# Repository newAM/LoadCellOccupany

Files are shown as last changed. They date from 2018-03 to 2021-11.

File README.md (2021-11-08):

## Load Cell Occupancy Sensor

### What is it?
This project is a occupancy sensor that uses a load cell for couches and beds, transmitting data to my Home Assistant server via MQTT over Ethernet.

### Why?
Other bed occupancy sensors that I have used in my home automation setup trigger false negatives when rolling around at night.  I use bed occupancy to turn on my lights if I get up at night, and I wanted a faster, more accurate solution.

#### Why PoE?
Wireless home automation devices often make sense only when they are battery powered, if a power cable needs to be run to the device it can carry data too.  Designing a low power wireless device is far more complicated than designing a wired device and running an Ethernet cable.

## Overview
Load cells → HX711 (ADC) → ATMega328P (MCU) → W5100 (Ethernet) → MQTT Broker → Home Assistant

This sensor takes input from 4 load cells, each supporting one leg of a bed or couch.  The load cells are sampled with a ATMega328P (Arduino) using an HX711 load cell ADC.  These samples are then transmitted to an MQTT broker via the Wiznet W5100 (same as Arduino Ethernet shield).

## Project Contents
-  LoadCell_ArduinoCode - firmware for the ATMega328P
-  LoadCell_Case - 3D printable case designed in OpenSCAD
-  LoadCell_Holder - 3D printable holder for the load cells designed in OpenSCAD
-  LoadCell_HomeAssistant - example Home Assistant configuration
-  LoadCell_KiCAD - schematic and PCB

## Media
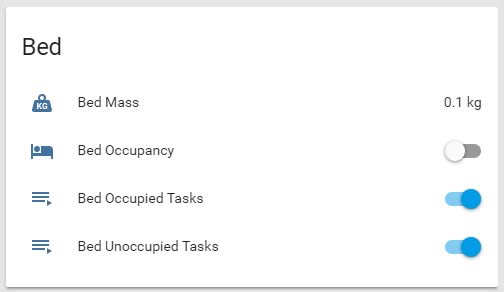
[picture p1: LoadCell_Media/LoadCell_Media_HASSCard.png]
Home Assistant Card


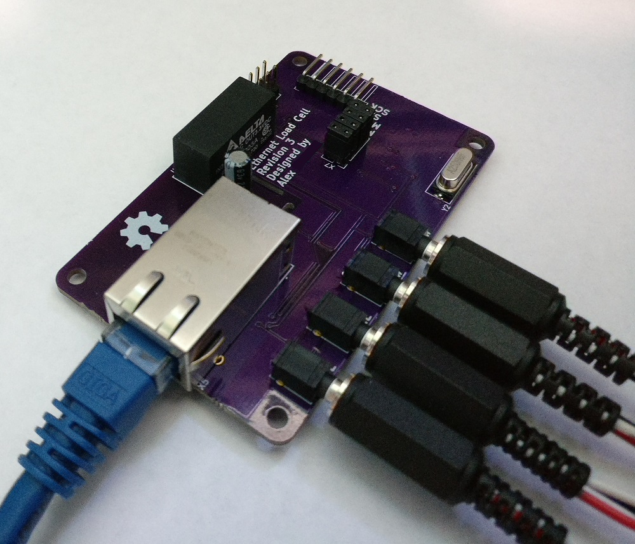
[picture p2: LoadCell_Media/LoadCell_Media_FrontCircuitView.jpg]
Front Circuit View


## Software Used
- [KiCad](http://kicad.org/)
- [Arduino IDE](https://www.arduino.cc/en/Main/Software)
- [OpenSCAD](http://www.openscad.org/)
- [Libre Office](https://www.libreoffice.org/)
- [Home Assistant](https://www.home-assistant.io/)

### Arduino Libraries used
- [Sparkfun HX711 Library](https://github.com/bogde/HX711)
- [Arduino MQTT Client](https://github.com/knolleary/pubsubclient)

## Forks
- [ESP8266 Load Cell](https://github.com/Skaronator/ESP8266-Load-Cell) - wireless edition

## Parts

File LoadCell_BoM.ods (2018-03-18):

Reference | Value | Tolerance | Rating | Package | Digikey P/N | Quantity
Integrated Circuits
U1 | HX711 |  |  | 16-SOIC | N/A | 1
U2 | ATMEGA328P-AU |  |  | 32-TQFP | ATMEGA328P-AU-ND | 1
U3 | NCP1090 |  |  | 8-SOIC | NCP1090DGOS-ND | 1
U4 | PG02S4803A |  |  | 8-SIP | 941-1185-ND | 1
U5 | W5100 |  |  | 80-LQFP (10) | 1278-1002-ND | 1
Resistors | Ohms |  | Watts
R1, R2 | 100 | 1% | 0.1 | 0603 | 311-100HRCT-ND | 2
R3-R6 | 49.9 | 1% | 0.25 | 0805 | RNCP0805FTD49R9CT-ND | 4
R7 | 20k | 1% | 0.1 | 0603 | 311-20.0KHRCT-ND | 1
R8 | 8.2k | 1% | 0.1 | 0603 | 311-8.20KHRCT-ND | 1
R13 | 300 | 1% | 0.1 | 0603 | 311-300HRCT-ND | 1
R9, R14-R16 | 12k | 1% | 0.1 | 0603 | 311-12.0KHRCT-ND | 4
R10 | 24.9k | 1% | 0.1 | 0603 | 311-24.9KHRCT-ND | 1
R11 | 178k | 1% | 0.1 | 0603 | 311-178KHRCT-ND | 1
R12 | 4420 | 1% | 0.1 | 0603 | 311-4.42KHRCT-ND | 1
R17 | 1M | 5% | 0.1 | 0603 | 311-1.0MGRCT-ND | 1
Capacitors | Farads |  | Volts
C1-3,C5-9, C13, C14, C16, C18-21 | 100n | 10% | 16 | 0603 | 1276-1005-1-ND | 14
C4, C12 | 10u | 10% | 10 | 0805 | 1276-6456-1-ND | 2
C15, C17 | 18p | 5% | 50 | 0603 | 1276-1089-1-ND | 2
C10 | 100n | 10% | 100 | 0805 | 1276-6840-1-ND | 1
C11 | 22u | 20% | 63 | 5mm | 493-12798-1-ND | 1
Inductors | Henries |  | Amperes
L1, L2 | 1u | 20% | 600m | 0603 | 445-3163-1-ND | 2
Oscillators | Hertz
Y1 | 8MHz |  |  |  | 490-1195-1-ND | 1
Y2 | 25M | 30ppm |  | HC49 | 535-10235-1-ND | 1
Connectors
X1-X4 | SJ1-2503A |  |  |  | CP1-2503A-ND | 3
X5 | 0813-1X1T-57-F |  |  |  | 507-1421-ND | 1
X6 | ICSP |  |  | 2*3 2.54mm | 952-1779-ND | 1
X7 | SPI Disconnect |  |  | 2*4 2.54mm | 952-2123-ND | 1
X8 | Serial Interface |  |  | 1*5 2.54mm RA | N/A | 1
Diodes
D1, D2 | MDB6S |  |  | 4-MicroDIP | MDB6SFSCT-ND | 2
D3 | SMAJ58A |  |  | SMA | SMAJ58A-E3/61GICT-ND | 1
Transistors
Q1 | MMBT4403 |  |  | SOT-23-3 | MMBT4403LT3GOSCT-ND | 1
Other
2.5mm male stereo connector |  |  |  |  | CP-2501SP-ND | 4
Jumpers |  |  |  |  | S9000-ND | 4
3-conductor wire |  |  |  |  | N/A | 4
PCB |  |  |  |  | N/A | 1
Cheap Ebay load cells |  |  |  |  | N/A | 4
Threaded brass inserts |  |  |  | M3 * 3mm | N/A | 4
M3 Screws |  |  |  | M3 * 3mm | N/A | 4

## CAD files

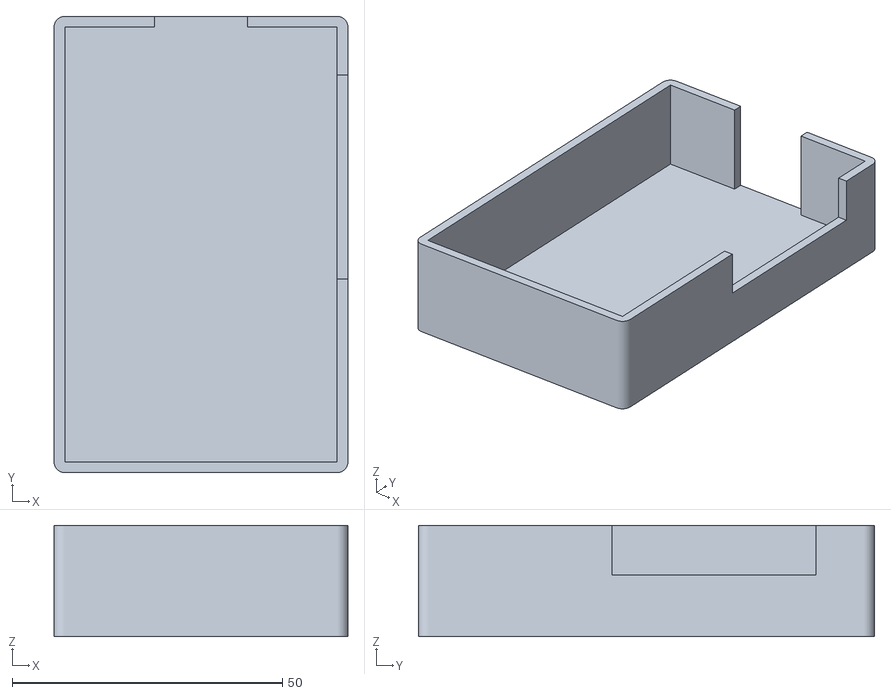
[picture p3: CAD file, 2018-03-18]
LoadCell_Case/LoadCell_Case_Lid.stl
54.4 x 84.4 x 20.6

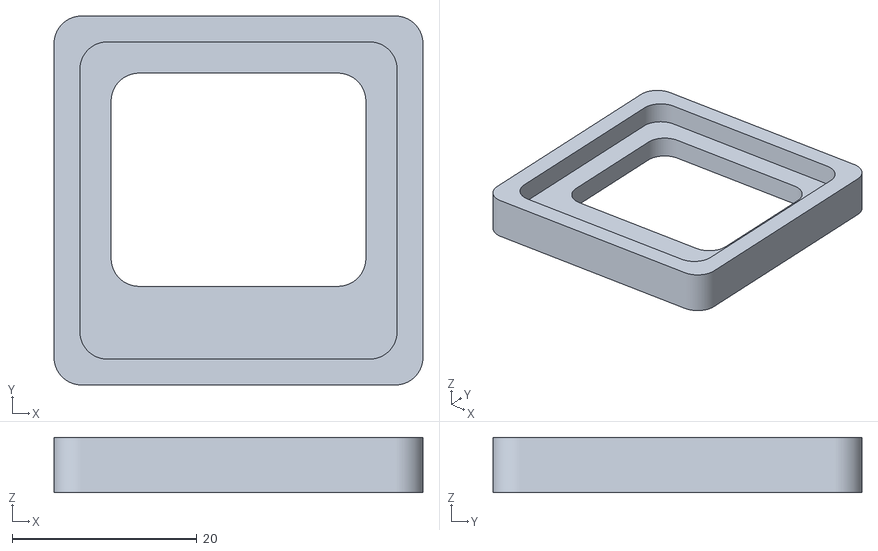
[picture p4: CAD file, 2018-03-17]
LoadCell_Holder/LoadCell_Holder.stl
40.0 x 40.0 x 6.00

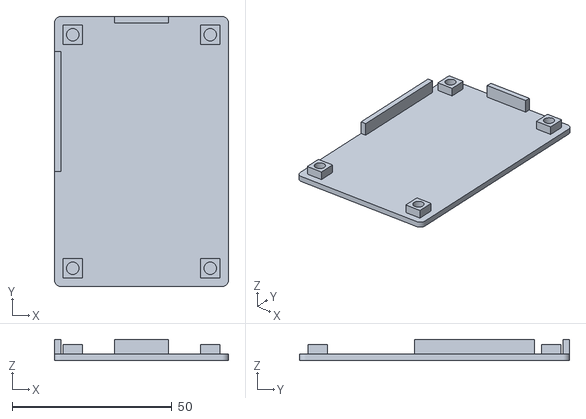
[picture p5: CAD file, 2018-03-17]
LoadCell_Case/LoadCell_Case_Base.stl
54.4 x 84.4 x 6.60

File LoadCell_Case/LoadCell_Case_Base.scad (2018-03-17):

include <LoadCell_Case_Dimensions.scad>;

// screw standoffs
standoff = [heatPad * 2, heatPad * 2, chipH];

// base dimensions
baseSize = [pcbW + (clear + wallW) * 2, pcbL + (clear + wallW) * 2, wallW];

// ethernet wall
baseEthWall = [ethW - clear * 2, wallW, pcbH + chipH];

// TRS wall
baseTrsWall = [wallW, trsRad * 2 + trsSpace * (trsNum - 1), pcbH + chipH];

union() {
    // create base
    RoundCorners(baseSize, roundR);

    // place PCB standoff at each corner
    for (x = [1, -1]) {
        for (y = [1, -1]) {
            translate([(pcbW / 2 - holeX) * x, (pcbL / 2 - holeX) * y, (baseSize[2] + standoff[2]) / 2]) {
                difference() {
                    cube(standoff, center = true);
                    cylinder(h = heatH + cutClear, r = heatR, center = true, $fn = fn);
                }
            }
        }
    }

    // place ethernet wall
    translate([0, (baseSize[1] - baseEthWall[1]) / 2, (baseSize[2] + baseEthWall[2]) / 2]) {
        cube(baseEthWall, center = true);
    }

    // place TRS wall
    translate([-(baseSize[0] - baseTrsWall[0]) / 2, pcbL / 2 - trsCent, (baseSize[2] + baseTrsWall[2]) / 2]) {
        cube(baseTrsWall, center = true);
    }
}

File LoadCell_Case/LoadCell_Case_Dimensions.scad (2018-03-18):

// render settings
fn       = 100;     // sides to render on cylinder
cutClear = 0.001;   // exact cutouts do not render

// clearances
clear = 0.2;    // object to case side
chipH = 3;      // height of chips on board

// PCB dimensions
pcbW = 50;      // width
pcbL = 80;      // length
pcbH = 1.6;     // height

// case dimensions
wallW   = 2;    // wall thickness
roundR  = 2;    // radius of rounded corners
wallCut = wallW + cutClear;

// ethernet cutout sizes
ethH = 13.61 + clear * 2; // 14.00 datasheet recommended
ethW = 16.79 + clear * 2; // 17.55 datasheet recommended

// TRS cutout sizes
trsRad   = 2 + clear;   // radius of cutout for TRS ports
trsSpace = 11;          // spacing between TRS ports 
                        // same as space between first TRS port and PCB edge
trsNum   = 4;           // number of TRS ports
trsCent  = 27.5;        // center of the TRS bank from edge of PCB

// PCB mount points
holeX   = 3.5;                  // distance from hole center to edge of PCB
heatR   = 3.9 / 2;              // radius of hole for heat set insert
heatH   = 3;                    // depth of hole for heat set insert
heatPad = holeX - clear * 2;    // radius of padding around heat set insert

// Makes a cube shape with rounded corners in the z-direction
// dim[x,y,z] - vector containing outer dimensions of the cube
// rad        - radius of the rounded corners 
module RoundCorners(dim, rad) {
    // create adjusted dimensions for corners
    adjDim = [dim[0] - rad * 2, dim[1] - rad * 2, dim[2]];

    hull() {
        // place cylinders at each corner
        for (x = [1, -1])
            for (y = [1, -1])
                translate([x * adjDim[0] / 2,   y * adjDim[1] / 2, 0])
                    cylinder(h = adjDim[2], r = rad, center = true, $fn = fn);

        // place main body
        cube(adjDim, center = true);
    }
}

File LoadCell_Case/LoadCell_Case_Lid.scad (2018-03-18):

include <LoadCell_Case_Dimensions.scad>;

// outer size of lid
lidOuterSize = [pcbW + (clear + wallW) * 2, pcbL + (clear + wallW) * 2, pcbH + chipH + ethH + wallW];

// inner size of lid
lidInnerSize = [pcbW + clear * 2, pcbL + clear * 2, pcbH + chipH + ethH];

// edge of wall
wallEdge = [(pcbW + wallW) / 2 + clear, (pcbL + wallW) / 2 + clear, - lidOuterSize[2] / 2 + wallW];

// ethernet wall cutout for lid
lidEthCutout = [ethW, wallCut, lidInnerSize[2] + cutClear];

// trs cutout for lid
lidTrsCutout = [wallCut, trsRad * 2 + trsSpace * (trsNum - 1) + clear * 2, pcbH + chipH + trsRad * 2 + clear];

difference() {

    // outer dimensions
    RoundCorners(lidOuterSize, roundR);

    // cutout inner dimensions
    translate([0, 0, wallW / 2 + cutClear])
        cube(lidInnerSize, center = true);

    // cutout ethernet hole
    translate([0, wallEdge[1], (lidOuterSize[2] - lidInnerSize[2]) / 2])
        cube(lidEthCutout, center = true);

    // cutout trs hole
    translate([wallEdge[0], pcbL / 2 - trsCent, (lidOuterSize[2] - lidTrsCutout[2]) / 2 + cutClear])
        cube(lidTrsCutout, center = true);
}

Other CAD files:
LoadCell_Holder/LoadCell_Holder.scad

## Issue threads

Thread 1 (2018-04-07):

Can I Make an Adruino Write ESP8266 Firmware?

1043717432, 2018-04-07:
Can you share your homeassistant automated yaml writing?
I am buying esp8266+HX711+Load Cell Occupancy Sensor but I don't know if it is okay to use Arduino.

newAM, 2018-04-29:
Fixed in beb6540b7db2d72ec277a60d8d90185031edf163.

Sorry for taking a while to get to this!

Closed 2018-04-29.

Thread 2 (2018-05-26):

I made a ESP8266 fork which include OTA updates

Skaronator, 2018-05-26:
Thanks @newAM for publishing your work. I wouldn't be able to do this project otherwise. Especially the 3D printed case.

___

In case someone build it's own version with a ESP8266 you might be interested in my fork. It connects via WiFi (obv) and support Over The Air updates.

It also saves the 'tare'/offset to the EEPROM and doesn't reset on restart/power off. And it only sends MQTT updates if the load has changed. (reduce the load on MQTT broker)

https://github.com/Skaronator/ESP8266-Load-Cell

newAM, 2018-06-03:
Thanks for the kind words!  I added your project in the md of mine so people can find it.  I also incorporated the broker load reduction, great idea!

Closed 2018-06-03.

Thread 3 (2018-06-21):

Load cell cable length

danpowell88, 2018-06-21:
How did you extend the length of the wires of the load cells, the ones I found have about 30cm of very thin cable, is it an issue to solder some more wire on an extend this or even better somehow replace it with a thicker cable thats a bit more protected?

newAM, 2018-06-22:
I just got some 3-conductor cable to extend the load cells, with the wires cut to length I have not had any issues.

Closed 2018-06-22.

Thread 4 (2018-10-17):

Strange fluctuations in weight

hammondses, 2018-10-17:
Hi mate,

For some reason I'm getting some pretty huge random fluctuations in weight & can't really work out why, it seems to work pretty well (other than needing to calibrate it so it's actually accurate).

Have a look at the attached image, what does your homeassistant sensor graph look like?

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

newAM, 2018-10-18:
That noise looks very impulsive, my initial guess is that it was a bad connection and shifting weight around is causing breaks, but you still get the noise without a load.  I have logging disabled for mine because it generates a ton of samples, but I am pretty sure I do not have impulses like that since my automation's would trigger when going from loaded to below 0Kg.

My other guess would be power supply noise, has the original schematic been adapted?  If it has, was is your power source?

How wide are those impulses?  If they are just a sample or two this could be cleaned up with a median filter.

hammondses, 2018-10-18:
Yeah i'm using a the esp8266 (somewhat) fork [Link](https://github.com/Skaronator/ESP8266-Load-Cell)

I'm using a 5v 2.1A power supply from my raspberry pi.

How would I tell how wide the impulses are? In the gui logging it shows no data for the sensor.

The points on the graph are always for only a 1 minute time frame, so I'm guessing its a sudden spike which is being recorded.

hammondses, 2018-10-18:
I initially had it setup on my in wall 5v 2a USB port which also gave the same results, swapped to the RPI one figuring it's worth a shot, but no change unfortunately.

I have zero C knowledge unfortunately, I was thinking I could also just do it in homeassistant with a filter, but implementing it at the source would definitely be better.

If you get a chance to have a go at it i'd be really grateful!

newAM, 2018-10-21:
I pushed the code with filter here: https://github.com/newAM/ESP8266-Load-Cell

I did not have the libraries installed to compile it, so if it doesn't build let me know.

Closed 2018-11-24.

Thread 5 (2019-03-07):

few questions

ikrowni, 2019-03-07:
The image of the final product looks different from the boards you mention as the hardware. I would like to have the input jacks and PoE but where do i purchase that specific board?

If my bed has 6 legs will that interfere? I have a purple mattress and it is very very heavy so there are 6 large cylinders for the legs. Can i use 6 load cell sensors just to have it all balanced properly?

newAM, 2019-03-08:
I'm not sure I understand, what is different from my image of the final product?  These boards cannot be purchased fully assembled, I had the PCB fabricated at OSH park and purchased the components on Digikey then soldered it together by hand.

6 legs should be ok, you can modify the design to utilize more load cells if you wish, the HX711 does have another different input that I did not utilize.  It would probably work well enough if you just put spacers under the two extra legs as well.  You mention your bed is heavy though, it is a good idea to double check that the occupants mass + the mass of your bed will not exceed the load cells limit.

Closed 2019-03-21.

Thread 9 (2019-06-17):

W5500 vs W5100

gth758y, 2019-06-17:
Just curious if you saw any technical reason that the Wiznet W5500 chip couldn't be used instead of the W5100 for this application. I'm thinking the 48-LQFP package of the W5500 would be significantly easier to solder than the 80-LQFP of the W5100. I'd have to redesign the board, but that may also reduce the number of caps needed as well.

[W5500 on Digikey](https://www.digikey.com/product-detail/en/wiznet/W5500/1278-1021-ND/4425702)

Looking over the datasheets, it looks to me like there are pins on the W5500 that closely match the pins being used on the W5100, but admittedly this isn't my area of expertise. Thoughts?

newAM, 2019-06-18:
There's no good reason for the decision, other than that the W5100 was what I had on hand when I was prototyping.  I have used the W5500 in my later designs (see: https://github.com/newAM/AmbientSensor) and I much prefer it.

The W5500 has a different PHY, and a slightly different programmers interface (there is an Arduino library though).  Apart from that it should be relatively drop-in.

gth758y, 2019-06-18:
Great, I'll look into implementing it for this. Thanks a bunch!

Closed 2019-06-18.

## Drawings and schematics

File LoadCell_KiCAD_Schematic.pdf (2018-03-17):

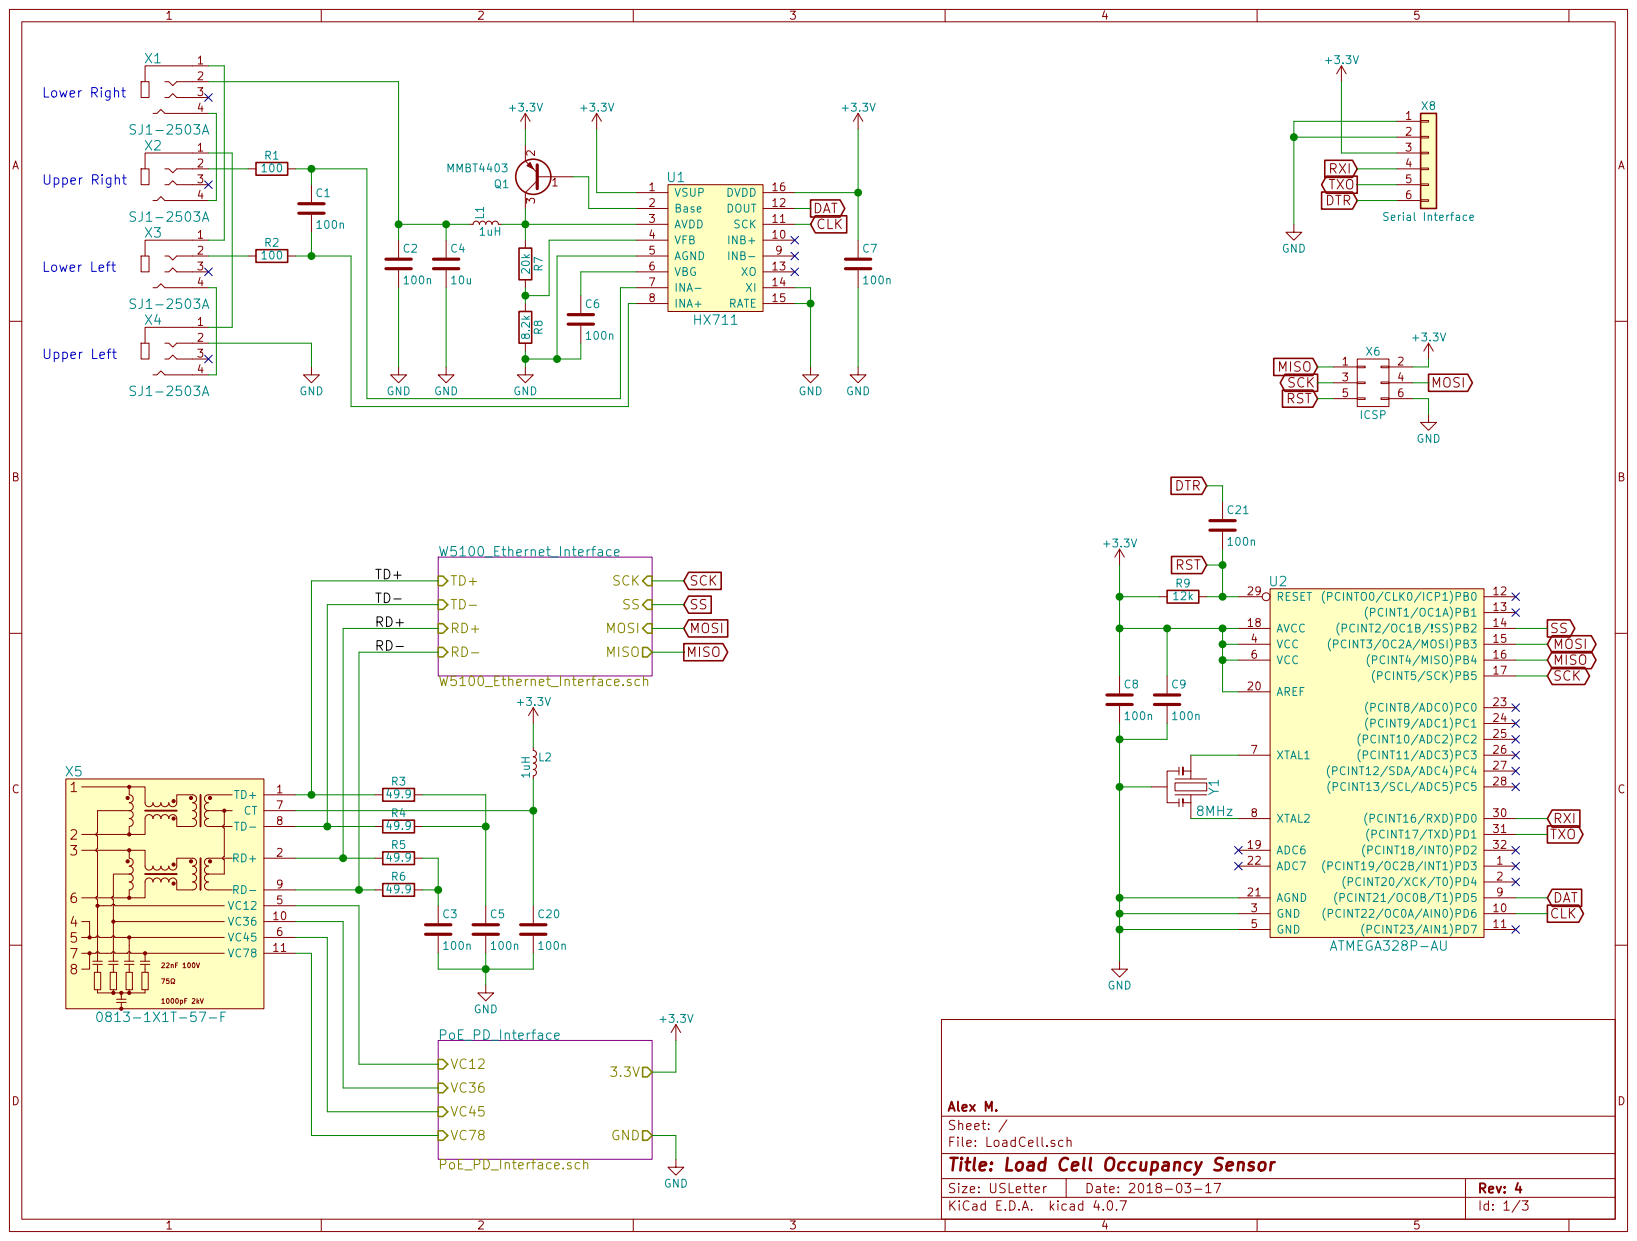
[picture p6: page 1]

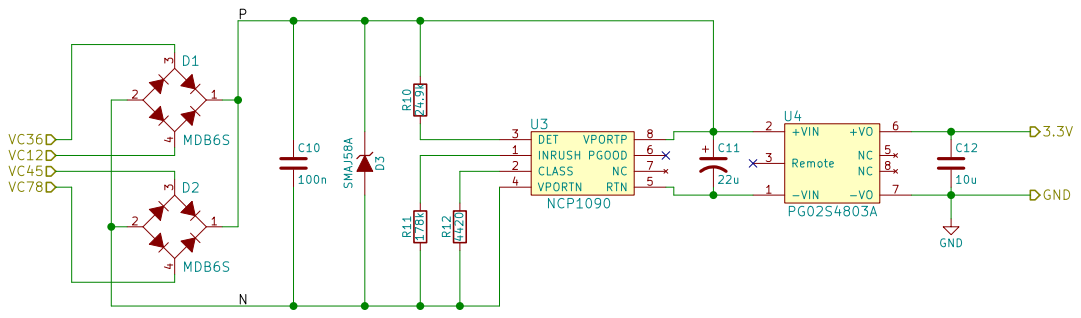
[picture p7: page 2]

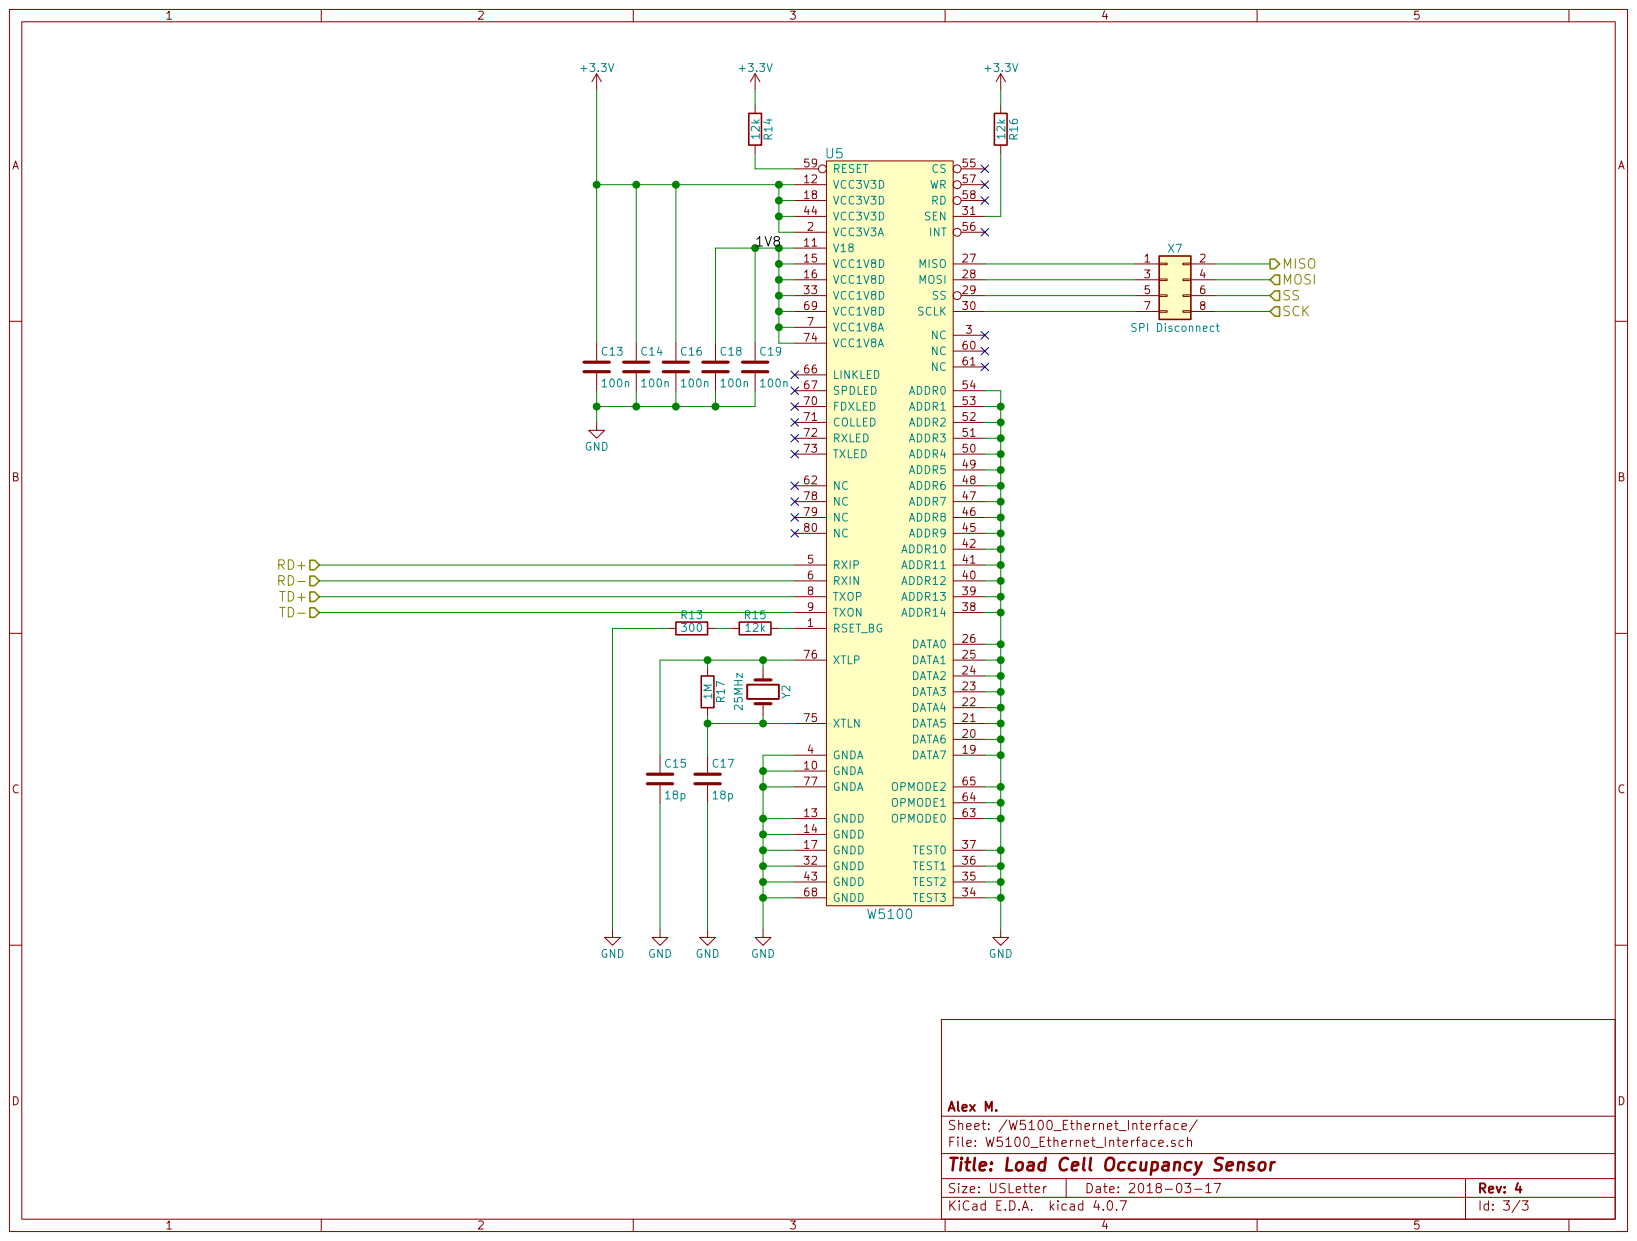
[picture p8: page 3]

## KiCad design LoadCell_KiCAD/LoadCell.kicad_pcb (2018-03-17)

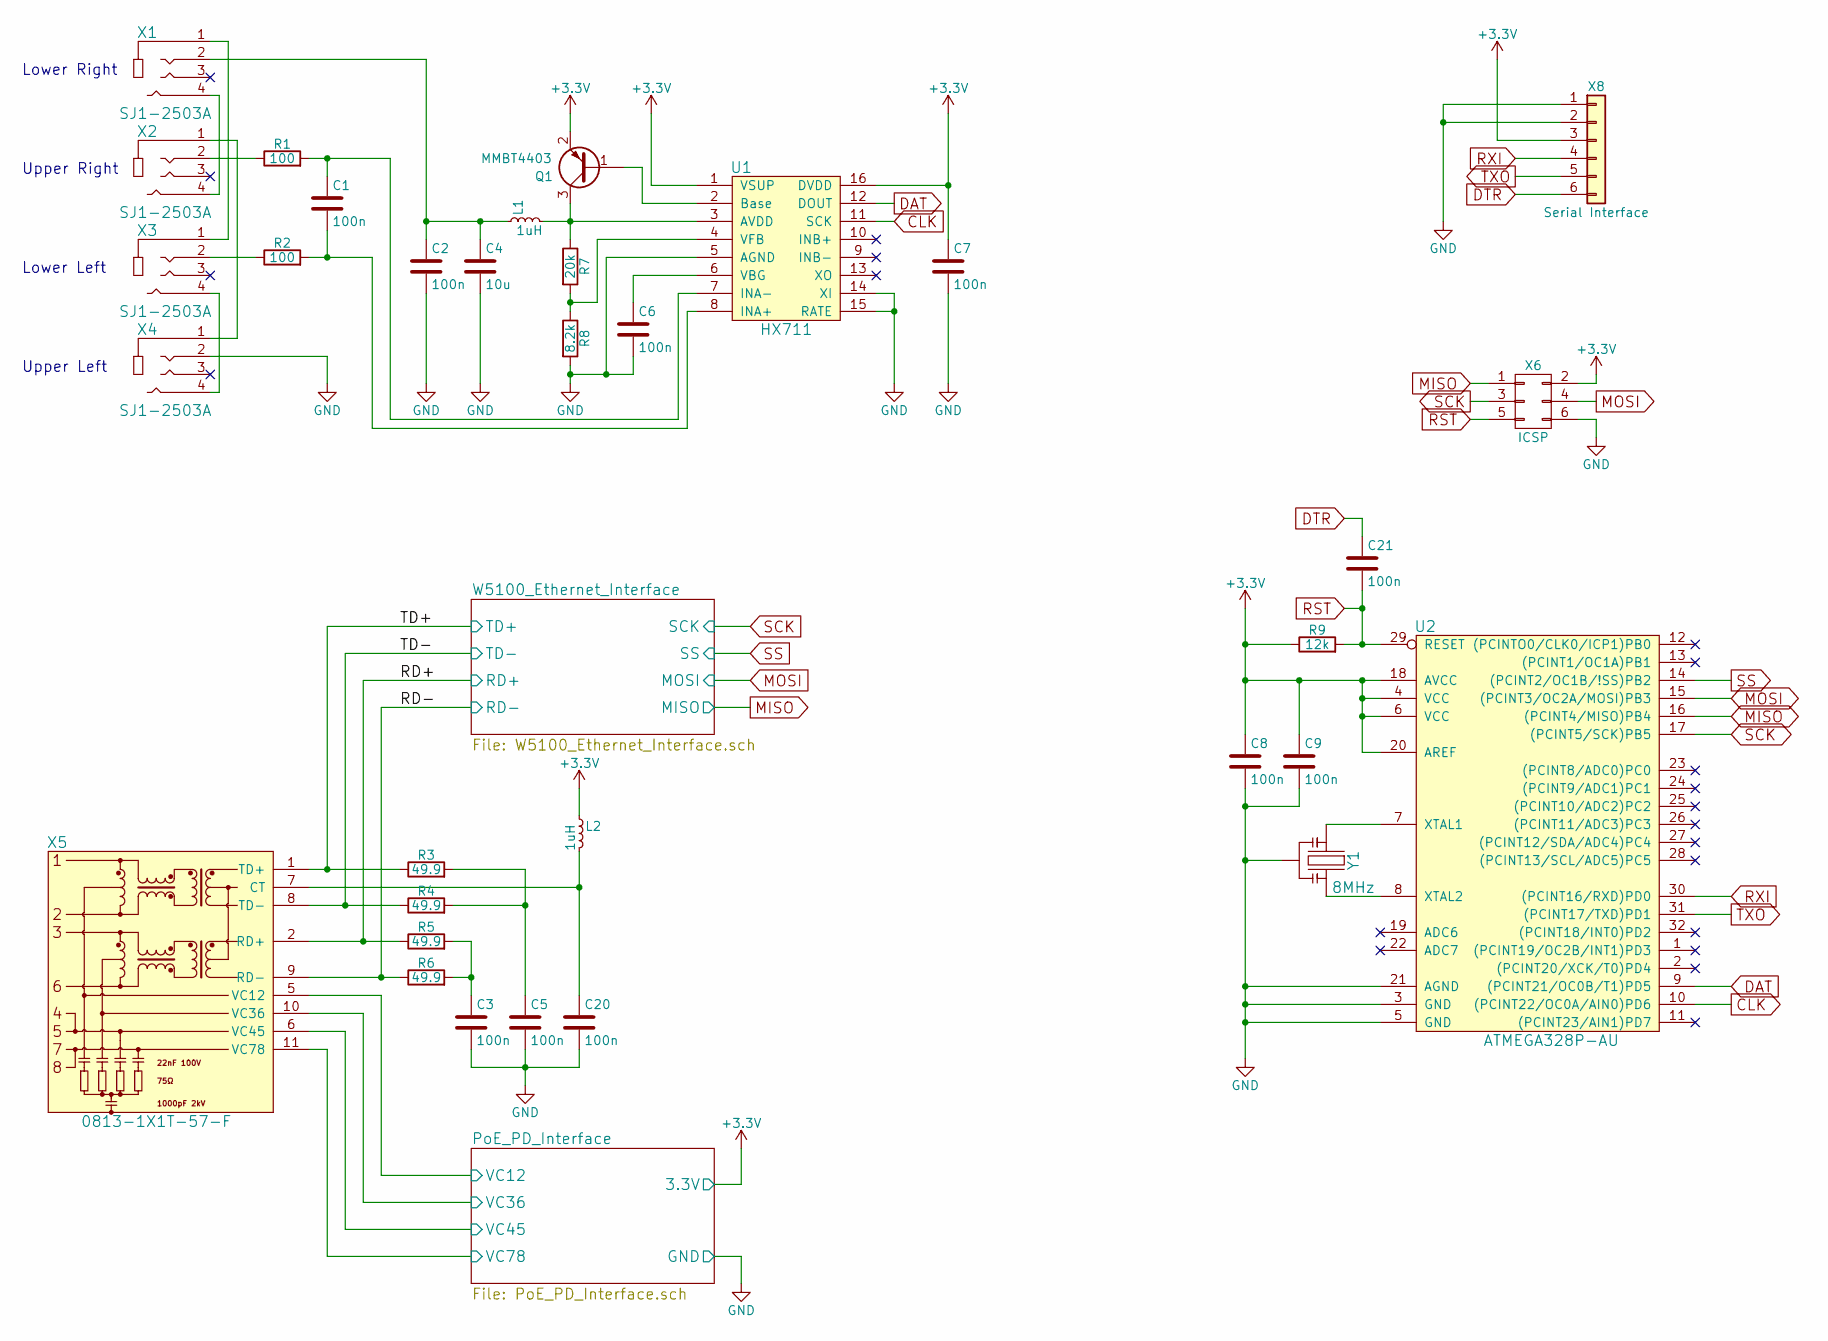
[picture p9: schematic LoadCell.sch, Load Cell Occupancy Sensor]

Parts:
C1, C2, C3, C5, C6, C7, C8, C9, C20, C21: 100n; C_0603; DigiKey Part Number 1276-1005-1-ND
C4: 10u; C_0805; DigiKey Part Number 1276-6456-1-ND
L1, L2: 1uH; C_0603; DigiKey Part Number 445-3163-1-ND
Q1: MMBT4403; SOT-23; DigiKey Part Number MMBT4403LT3GOSCT-ND
R1, R2: 100; R_0603; Tolerance 1%; DigiKey Part Number 311-100HRCT-ND
R3, R4, R5, R6: 49.9; R_0805; DigiKey Part Number RNCP0805FTD49R9CT-ND
R7: 20k; R_0603; Tolerance 1%; DigiKey Part Number 311-20.0KHRCT-ND
R8: 8.2k; R_0603; Tolerance 1%; DigiKey Part Number 311-8.20KHRCT-ND
R9: 12k; R_0603; Tolerance 1%; DigiKey Part Number 311-12.0KHRCT-ND
U1: HX711; SOIC-16_3.9x9.9mm_Pitch1.27mm
U2: ATMEGA328P-AU; TQFP-32_7x7mm_Pitch0.8mm; DigiKey Part Number ATMEGA328P-AU-ND
X1, X2, X3, X4: SJ1-2503A; DigiKey Part Number CP1-2503A-ND
X5: 0813-1X1T-57-F; 0813-1X1T-57-F_RJ45-Jack; DigiKey Part Number 507-1421-ND
X6: ICSP; Pin_Header_Straight_2x03_Pitch2.54mm
X8: Serial Interface; Pin_Header_Angled_1x06_Pitch2.54mm
Y1: 8MHz; CERALOCK_CSTCE_Resonator; DigiKey Part Number 490-1195-1-ND

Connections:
+3V3: C7.1, C8.1, C9.1, L2.1, Q1.2 (E), R9.1, U1.1 (VSUP), U1.16 (DVDD), U2.4 (VCC), U2.6 (VCC), U2.18 (AVCC), U2.20 (AREF), X6.2, X8.3; also elsewhere on the board
/PoE_PD_Interface/VC12: X5.5 (VC12); also elsewhere on the board
/PoE_PD_Interface/VC36: X5.10 (VC36); also elsewhere on the board
/PoE_PD_Interface/VC45: X5.6 (VC45); also elsewhere on the board
/PoE_PD_Interface/VC78: X5.11 (VC78); also elsewhere on the board
/RD+: R5.1, X5.2 (RD+); also elsewhere on the board
/RD-: R6.1, X5.9 (RD-); also elsewhere on the board
/TD+: R3.1, X5.1 (TD+); also elsewhere on the board
/TD-: R4.1, X5.8 (TD-); also elsewhere on the board
CLK: U1.11 (SCK), U2.10 ((PCINT22/OC0A/AIN0)PD6)
DAT: U1.12 (DOUT), U2.9 ((PCINT21/OC0B/T1)PD5)
DTR: C21.1, X8.6
GND: C2.2, C3.2, C4.2, C5.2, C6.2, C7.2, C8.2, C9.2, C20.2, R8.2, U1.5 (AGND), U1.14 (XI), U1.15 (RATE), U2.3 (GND), U2.5 (GND), U2.21 (AGND), X4.2, X6.6, X8.1, X8.2, Y1.2; also elsewhere on the board
MISO: U2.16 ((PCINT4/MISO)PB4), X6.1; also elsewhere on the board
MOSI: U2.15 ((PCINT3/OC2A/MOSI)PB3), X6.4; also elsewhere on the board
unnamed: C1.1, R1.2, U1.7 (INA-)
unnamed: C1.2, R2.2, U1.8 (INA+)
unnamed: C2.1, C4.1, L1.1, X1.2
unnamed: C3.1, R5.2, R6.2
unnamed: C5.1, R3.2, R4.2
unnamed: C6.1, U1.6 (VBG)
unnamed: C20.1, L2.2, X5.7 (CT)
unnamed: L1.2, Q1.3 (C), R7.1, U1.3 (AVDD)
unnamed: Q1.1 (B), U1.2 (Base)
unnamed: R1.1, X2.2
unnamed: R2.1, X3.2
unnamed: R7.2, R8.1, U1.4 (VFB)
unnamed: U2.7 (XTAL1), Y1.1
unnamed: U2.8 (XTAL2), Y1.3
unnamed: X1.1 (Case), X3.1 (Case)
unnamed: X1.4, X2.4
unnamed: X2.1 (Case), X4.1 (Case)
unnamed: X3.4, X4.4
RST: C21.2, R9.2, U2.29 (RESET), X6.5
RXI: U2.30 ((PCINT16/RXD)PD0), X8.4
SCK: U2.17 ((PCINT5/SCK)PB5), X6.3; also elsewhere on the board
SS: U2.14 ((PCINT2/OC1B/!SS)PB2); also elsewhere on the board
TXO: U2.31 ((PCINT17/TXD)PD1), X8.5

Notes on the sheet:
Upper Left
Lower Right
Upper Right
Lower Left

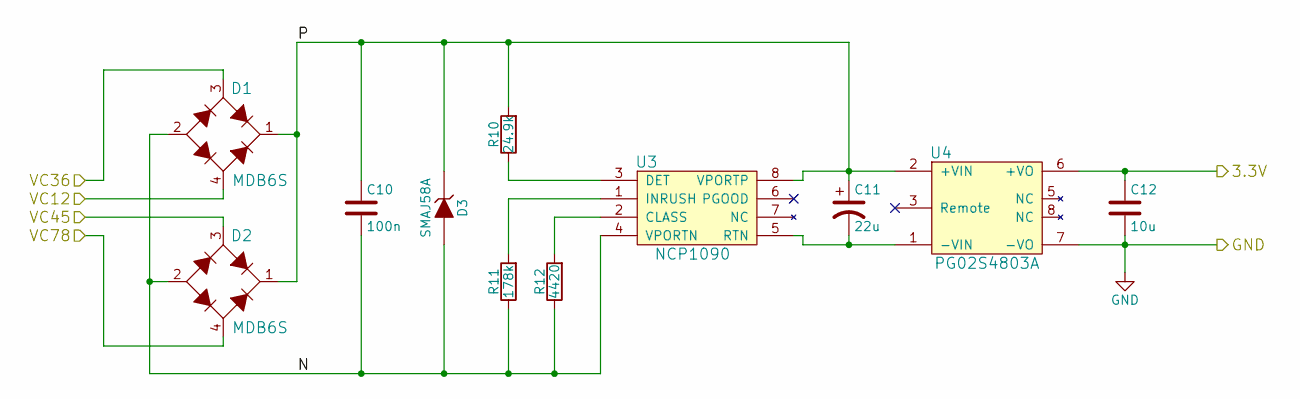
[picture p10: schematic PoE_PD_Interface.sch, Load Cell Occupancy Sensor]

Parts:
C10: 100n; C_0805; DigiKey Part Number 1276-6840-1-ND
C11: 22u; CP_Radial_D5.0mm_P2.00mm; DigiKey Part Number 493-12798-1-ND
C12: 10u; C_0805; DigiKey Part Number 1276-6456-1-ND
D1, D2: MDB6S; Micro-DIP-4; DigiKey Part Number MDB6SFSCT-ND
D3: SMAJ58A; D_SMA; DigiKey Part Number SMAJ58A-E3/61GICT-ND
R10: 24.9k; R_0603; DigiKey Part Number 311-24.9KHRCT-ND
R11: 178k; R_0603; DigiKey Part Number 311-178KHRCT-ND
R12: 4420; R_0603; DigiKey Part Number 311-4.42KHRCT-ND
U3: NCP1090; SOIC-8_3.9x4.9mm_Pitch1.27mm; DigiKey Part Number NCP1090DGOS-ND
U4: PG02S4803A; PG02S; DigiKey Part Number 941-1185-ND

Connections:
+3V3: C12.1, U4.6 (+VO); also elsewhere on the board
/PoE_PD_Interface/N: C10.2, D1.2 (-), D2.2 (-), D3.2 (A), R11.1, R12.1, U3.4 (VPORTN)
/PoE_PD_Interface/P: C10.1, C11.1, D1.1 (+), D2.1 (+), D3.1 (K), R10.2, U3.8 (VPORTP), U4.2 (+VIN)
/PoE_PD_Interface/VC12: D1.4 (AC2); also elsewhere on the board
/PoE_PD_Interface/VC36: D1.3 (AC1); also elsewhere on the board
/PoE_PD_Interface/VC45: D2.3 (AC1); also elsewhere on the board
/PoE_PD_Interface/VC78: D2.4 (AC2); also elsewhere on the board
GND: C12.2, U4.7 (-VO); also elsewhere on the board
unnamed: C11.2, U3.5 (RTN), U4.1 (-VIN)
unnamed: R10.1, U3.3 (DET)
unnamed: R11.2, U3.1 (INRUSH)
unnamed: R12.2, U3.2 (CLASS)

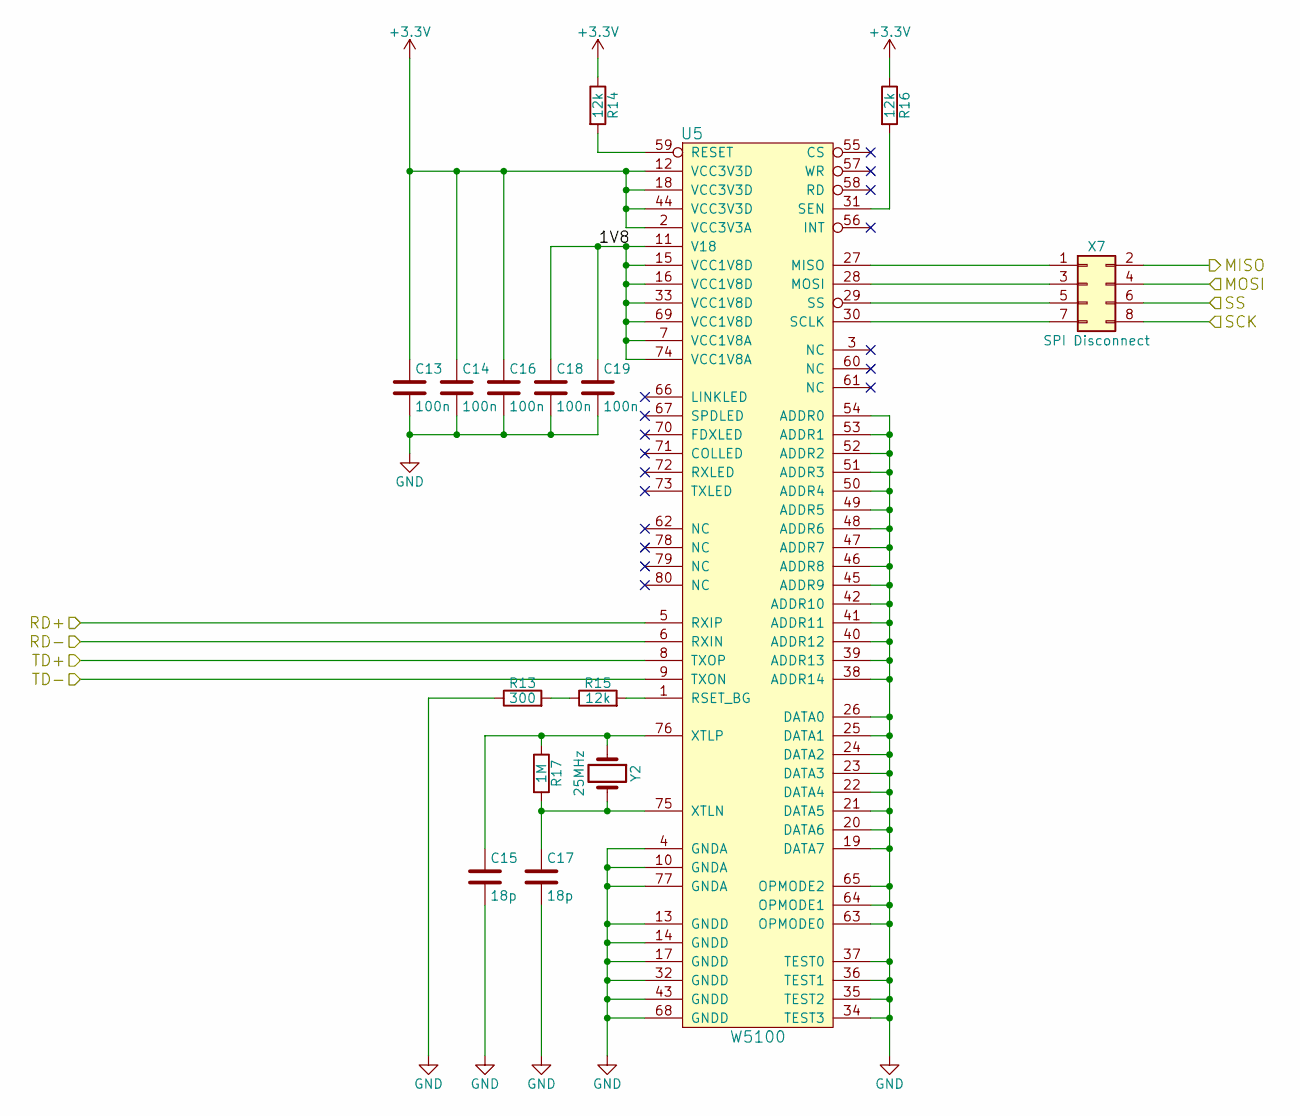
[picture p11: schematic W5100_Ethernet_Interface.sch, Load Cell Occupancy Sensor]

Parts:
C13, C14, C16, C18, C19: 100n; C_0603; DigiKey Part Number 1276-1005-1-ND
C15, C17: 18p; C_0603; DigiKey Part Number 1276-1089-1-ND
R13: 300; R_0603; Tolerance 1%; DigiKey Part Number 311-300HRCT-ND
R14, R15, R16: 12k; R_0603; Tolerance 1%; DigiKey Part Number 311-12.0KHRCT-ND
R17: 1M; R_0603; Tolerance 1%; DigiKey Part Number 311-1.00MHRCT-ND
U5: W5100; LQFP-80_10x10mm_Pitch0.4mm; DigiKey Part Number 1278-1002-ND
X7: SPI Disconnect; Pin_Header_Straight_2x04_Pitch2.54mm
Y2: 25MHz; Crystal_SMD_HC49-SD; DigiKey Part Number 535-10235-1-ND

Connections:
+3V3: C13.1, C14.1, C16.1, R14.1, R16.1, U5.2 (VCC3V3A), U5.12 (VCC3V3D), U5.18 (VCC3V3D), U5.44 (VCC3V3D); also elsewhere on the board
/RD+: U5.5 (RXIP); also elsewhere on the board
/RD-: U5.6 (RXIN); also elsewhere on the board
/TD+: U5.8 (TXOP); also elsewhere on the board
/TD-: U5.9 (TXON); also elsewhere on the board
/W5100_Ethernet_Interface/1V8: C18.1, C19.1, U5.7 (VCC1V8A), U5.11 (V18), U5.15 (VCC1V8D), U5.16 (VCC1V8D), U5.33 (VCC1V8D), U5.69 (VCC1V8D), U5.74 (VCC1V8A)
GND: C13.2, C14.2, C15.2, C16.2, C17.2, C18.2, C19.2, R13.1, U5.4 (GNDA), U5.10 (GNDA), U5.13 (GNDD), U5.14 (GNDD), U5.17 (GNDD), U5.19 (DATA7), U5.20 (DATA6), U5.21 (DATA5), U5.22 (DATA4), U5.23 (DATA3), U5.24 (DATA2), U5.25 (DATA1), U5.26 (DATA0), U5.32 (GNDD), U5.34 (TEST3), U5.35 (TEST2), U5.36 (TEST1), U5.37 (TEST0), U5.38 (ADDR14), U5.39 (ADDR13), U5.40 (ADDR12), U5.41 (ADDR11), U5.42 (ADDR10), U5.43 (GNDD), U5.45 (ADDR9), U5.46 (ADDR8), U5.47 (ADDR7), U5.48 (ADDR6), U5.49 (ADDR5), U5.50 (ADDR4), U5.51 (ADDR3), U5.52 (ADDR2), U5.53 (ADDR1), U5.54 (ADDR0), U5.63 (OPMODE0), U5.64 (OPMODE1), U5.65 (OPMODE2), U5.68 (GNDD), U5.77 (GNDA); also elsewhere on the board
MISO: X7.2; also elsewhere on the board
MOSI: X7.4; also elsewhere on the board
unnamed: C15.1, R17.1, U5.76 (XTLP), Y2.1
unnamed: C17.1, R17.2, U5.75 (XTLN), Y2.2
unnamed: R13.2, R15.1
unnamed: R14.2, U5.59 (RESET)
unnamed: R15.2, U5.1 (RSET_BG)
unnamed: R16.2, U5.31 (SEN)
unnamed: U5.27 (MISO), X7.1
unnamed: U5.28 (MOSI), X7.3
unnamed: U5.29 (SS), X7.5
unnamed: U5.30 (SCLK), X7.7
SCK: X7.8; also elsewhere on the board
SS: X7.6; also elsewhere on the board

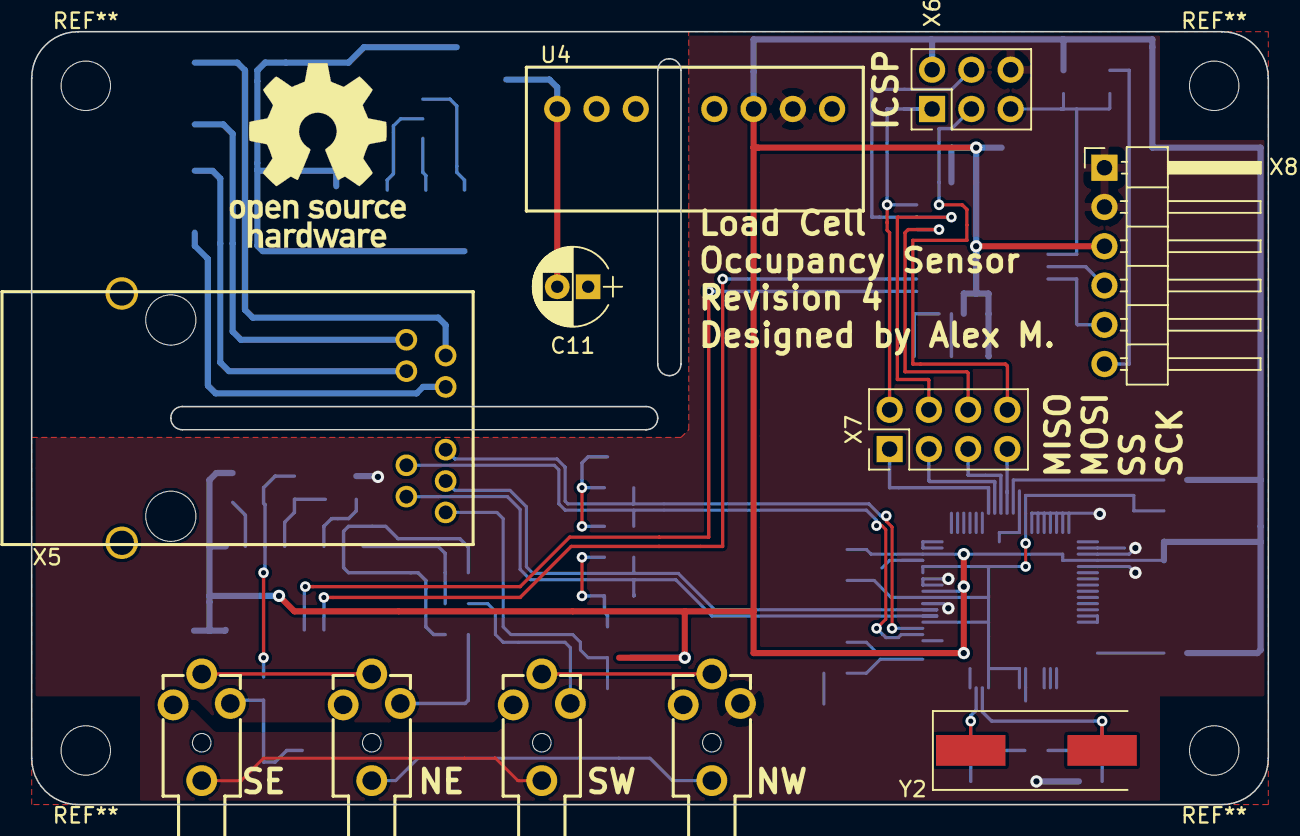
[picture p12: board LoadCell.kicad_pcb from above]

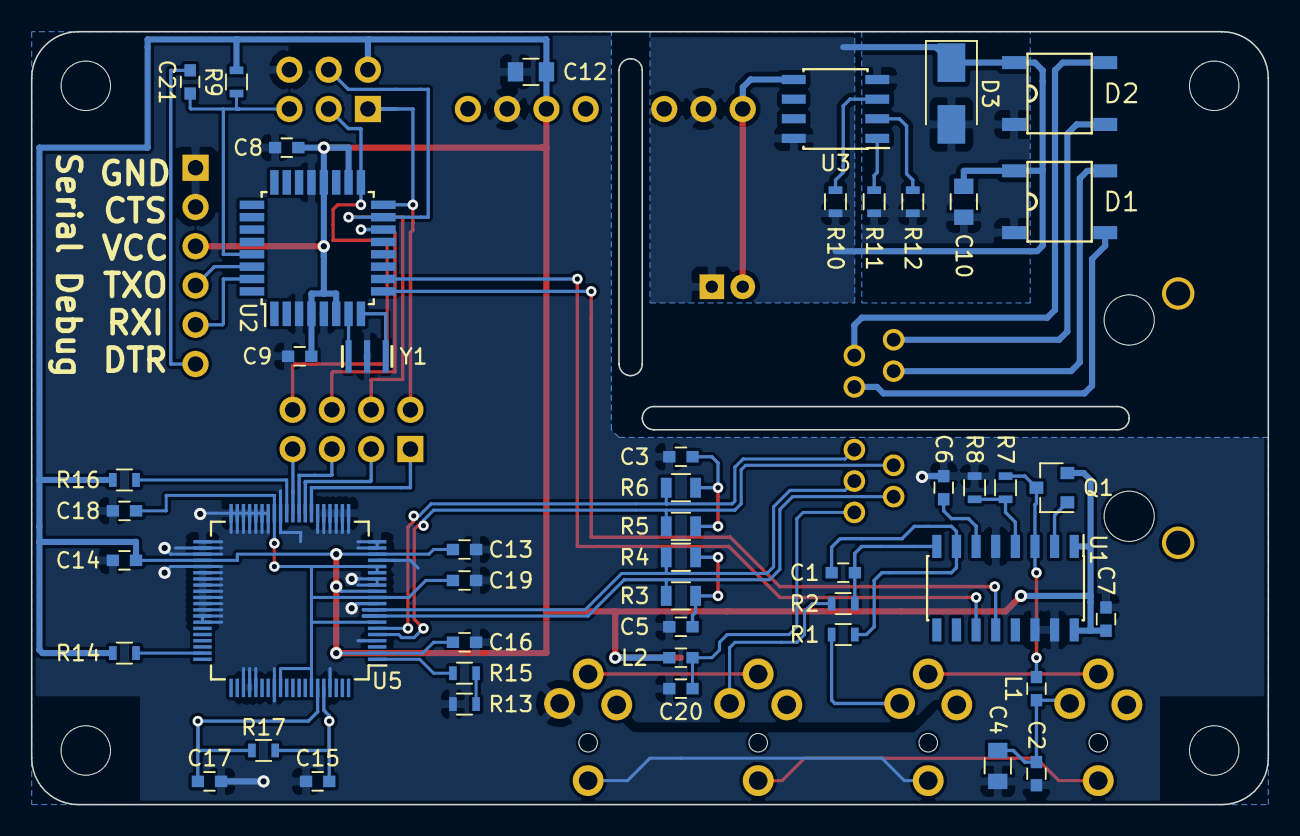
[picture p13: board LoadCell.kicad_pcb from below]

Board: 2 copper layers, 80.0 x 50.0 mm, 59 parts (48 on the bottom side), 55 nets.

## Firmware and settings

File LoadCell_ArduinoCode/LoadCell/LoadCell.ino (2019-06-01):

#include <SPI.h>
#include <Ethernet.h>
#include <PubSubClient.h>
#include "HX711.h"

// HX711 pin connection
#define DOUT 5
#define CLK  6

// HX711 sample settings
#define CALIBRATION   -22990 // ADC bits to Kg conversion factor
#define NUM_SAMPLES        3 // number of samples to take per data point
#define SAMPLE_PERIOD    100 // sample period in ms
#define RESULT_WIDTH       5 // number of characters in result
#define RESOLUTION         1 // number of characters after the decimal
#define PRECISION        0.1 // precision of the result

// connection settings
#define TIMEOUT   5000 // connection failure timeout in ms
#define SER_BAUD  9600 // serial baud rate
#define MQTT_PORT 1883 // MQTT broker port
#define MQTT_CLIENT_ID "bedCell" // device client ID

// MQTT topics
#define TOPIC_BASE "/home/bedroom/bed" // base topic
#define TOPIC_LOAD TOPIC_BASE "/load"  // topic to publish samples on
#define TOPIC_TARE TOPIC_BASE "/tare"  // topic to receive tare commands on

// client objects
EthernetClient ethClient;
PubSubClient mqttClient(ethClient);

// HX711 load cell ADC
HX711 scale;

// reconnects to the MQTT broker
void reconnect()
{
    // loop while disconnected
    while (!mqttClient.connected())
    {
        // attempt to connect
        Serial.println("Attempting to establish connection to MQTT broker...");
        if (mqttClient.connect(MQTT_CLIENT_ID)) 
        {
            // print connection messaged for debug
            Serial.println("Connection established");
            mqttClient.publish(TOPIC_BASE, "connected");

            // subscribe to control topic
            mqttClient.subscribe(TOPIC_TARE);
        }
        else
        {
            Serial.print("Failed to connect: ");

            // print client state
            switch (mqttClient.state())
            {
                case MQTT_CONNECTION_TIMEOUT:
                    Serial.println("MQTT_CONNECTION_TIMEOUT");
                    break;
                case MQTT_CONNECTION_LOST:
                    Serial.println("MQTT_CONNECTION_LOST");
                    break;
                case MQTT_CONNECT_FAILED:
                    Serial.println("MQTT_CONNECT_FAILED");
                    break;
                case MQTT_DISCONNECTED:
                    Serial.println("MQTT_DISCONNECTED");
                    break;           
                case MQTT_CONNECTED:
                    Serial.println("MQTT_CONNECTED");
                    break;
                case MQTT_CONNECT_BAD_PROTOCOL:
                    Serial.println("MQTT_CONNECT_BAD_PROTOCOL");
                    break;
                case MQTT_CONNECT_BAD_CLIENT_ID:
                    Serial.println("MQTT_CONNECT_BAD_CLIENT_ID");
                    break;
                case MQTT_CONNECT_UNAVAILABLE:
                    Serial.println("MQTT_CONNECT_UNAVAILABLE");
                    break;
                case MQTT_CONNECT_BAD_CREDENTIALS:
                    Serial.println("MQTT_CONNECT_BAD_CREDENTIALS");
                    break;
                case MQTT_CONNECT_UNAUTHORIZED:
                    Serial.println("MQTT_CONNECT_UNAUTHORIZED");
                    break;
                default:
                    Serial.println("MQTT_STATE_UNKNOWN");
                    break;
            }

            // delay before next attempt
            delay(TIMEOUT);
        } 
    }
}

// callback function for handling new messages on subscribed topics
void callback(char* topic, byte* payload, unsigned int length)
{
    // zero out scale offset
    if (!strcmp(topic, TOPIC_TARE))
    {
        Serial.println("Zeroing...");
        scale.tare();
    }
}

void setup()
{
    scale.begin(DOUT, CLK);
    // network settings
    const uint8_t mac[] = {0x00, 0xAA, 0xBB, 0xCC, 0xDE, 0x02}; // device MAC
    IPAddress mqttBroker(10, 0, 0, 4); // MQTT broker IP

    // open serial connection
    Serial.begin(SER_BAUD);

    // print status
    Serial.println("Serial connected!");
    Serial.println("Configuring Ethernet with DHCP...");

    // connect with DHCP
    while (!Ethernet.begin(mac))
    {
        delay(TIMEOUT);
    }

    // print IP address
    Serial.println("Ethernet connected!");
    Serial.print("My IP: ");
    Serial.println(Ethernet.localIP());

    // configure MQTT broker
    mqttClient.setServer(mqttBroker, MQTT_PORT);

    // set callback function
    mqttClient.setCallback(callback);

    // set scale calibration
    scale.set_scale(CALIBRATION);

    // zero out scale
    scale.tare();
}

void loop()
{
    static uint32_t timer   = 0; // sample timer
    static uint8_t  samples = 0; // number of samples taken
    static float    avg     = 0; // load average
    static float    oldAvg  = 0; // stores the past average

    // connect if disconnected
    if (!mqttClient.connected())
    {
        reconnect();
    }

    // take sample
    if (millis() - timer >= SAMPLE_PERIOD)
    {
        avg += scale.get_units();
        samples++;

        if (samples >= NUM_SAMPLES)
        {
            // buffer for the sample as a string
            uint8_t result[RESULT_WIDTH + 1]; 

            // average the samples
            avg /= samples;

            // transmit only if value has changed
            if (abs(avg - oldAvg) > PRECISION)
            {
                // convert the float to a string
                dtostrf(avg, RESULT_WIDTH, RESOLUTION, result);

                // publish string
                mqttClient.publish(TOPIC_LOAD, result);

                // store past transmission
                oldAvg = avg;
            }

            // clear variables
            avg     = 0;
            samples = 0;
        }

        // reset timer
        timer = millis();
    }

    // maintain connection
    mqttClient.loop();
}

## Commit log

2018-03-18 corrected lid dimensions after print
    [LoadCell_Case_Dimensions.scad, LoadCell_Case_Lid.scad, LoadCell_Case_Lid.stl]
2018-03-18 updated readme to include the use of libre office for the bill of materials spreadsheet
2018-03-18 added mounting hardware to BoM
    [LoadCell_BoM.ods]
2018-04-29 added tare functionality and serial prints for debug
2018-06-03 added pictures to readme. value is now only transmitted on change to reduce broker load
    [LoadCell.ino]
2018-10-07 fixed small typo in code
    [LoadCell.ino]
2019-05-29 LoadCell ino file with wifi instead of ethernet
    Made some changes where the mqtt doesn't reconnect constantly. Only when active connection. For my sitiuation i measure the bed. Since if you move around at night it will do a lot of updates so i changed the frequency and only full kilo's. This results in less traffic and fewer updates. (it detects that i am in bed in a few seconds, thats fast enough)
    Also copy pasted the over the air update from the other repo in your readme. Reason to adjust this one was that the other one crashed every now and then. I redid the wifi part and it seems to be solid (for now)
    Last part is that if the value is a negative value i just reset it back to 0. Thi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
    [LoadCellWifi.ino]
2021-11-08 Update README.md
    https://forum.kicad.info/t/warning-avoid-all-links-to-kicad-pcb-org-use-kicad-org/31521
